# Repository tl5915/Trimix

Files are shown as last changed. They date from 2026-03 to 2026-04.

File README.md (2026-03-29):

# Trimix Analyser
Gas thermo conductivity based trimix analyser. No internal battery, powered via USB-C using phone or power bank, or Magsafe. No display, user interface accessed via html.

## Principles
### Oxygen
- Galvenic O2 cell outputs voltage roughly between 8 to 70mV. This is read by ADS1115 16 bit analog-to-digital converter, with PGA gain set to 16 (256mV range). - Rebreather O2 cells contains load resistor, no external load resistor required.
### Helium
- MD62 is a thermo conductivity CO2 sensor, but could also measure gases with thermo conductivity lower than air, ie helium. The sensor contains 2 pairs of temperature-sensitive resistors, one enclosed in known gas (compensation side), one exposed to enviroment (measurement side). Apply voltage to heat up the resistors, heat will desipate quicker in measurement side when exposed to helium, changing resistance. The subtle difference in resistance between the two resistors is measured by a balanced wheastone bridge.
- Manufacturer specification for power supply is 3.0 +/- 0.1V (attached datasheet is outdated and wrong). 3.3V power supply passing through a 1N5819 Schottky diode give just the right amount of forward voltage drop to get 2.9V. Do not use the MCU's internal 3.3V power supply, use external supply: MD62 can can drain up to 200mA.
- Wheastone bridge build contains two 2k ohm resistors, and a 500 ohm potentiometer to adjust bridge balance. I use a DS3502 digital potentiometer (10k ohm), parallel connect to 510 ohm resistor to drop total resistence to 485 ohm. Bridge voltage is read between the centre pins of MD62 and DS3502 wiper, by ADS1115, with PGA gain set to 4 (1024mV range). Maximum voltage I have seen with pure helium is around 600mV so well within range.
- Flow rate matters for thermal conductivity sensors: quickly the gas flow, quicker heat got taken away from the sensor. Ideal flow rate 0.5 to 2L/min. BCD inflator nipple to 1/4 NPT male adaptor has the perfect inner diameter to tap 3/8 UNF thread, so a low pressure port blank plug without o ring can be installed, and flow rate can be adjusted by how tight it is. Low pressure constant flow gas exit via hose barb to 1/4 NPT female adaptor. Several try and errors required to set the flow rate.
### Gas quality
- I couldn't find any small enough carbon monoxide sensor, so opted for SGP40. SGP40 is a VOC sensor, but also cross react with carbon monoxide. This might be a better option, because the sources of CO found in cylinder are usually o ring combustion, or generator/engine fume, both containing VOC.
- The sensor read out if not quantitantive, but relative. Turn on in air, reading should stablise around 50 to 100, if reading in analysed gas goes up -> bad, otherwise lower the number the better. Raw sensor resistance also provided on the UI for reference (higher the better, VOC and CO reduce resistance).
### Coomunication
- All peripheries (ADS1115, DS3502, SGP40) are connected to Adafruit QT Py ESP32-C3 through I2C, via the Stemma QT connector.
- ESP32-C3 wifi is set to AP hotspot mode, connect to the wifi and read/calibrate via html.
### Power
- USB-C panel mount connects to VCC and GND on QT Py ESP32-C3 for 5V USB power.
- Alternatively MagSafe receiver connects to the USB-C port on QT Py ESP32-C3 for wireless 5V power.

## Material
- Housing to be 3D printed in STL folder
(optional M16 x 1.0 tap to smooth out O2 connector tube)
- BCD nipple to 1.4 NPT male convertor (gas in)
(https://ebay.us/m/m2sN6S)
- 3/8 UNF tap (tap on the NPT side of the above convertor to mount a o-ring-removed LP blanking plug to adjust flow rate to 1 L/min)
(https://amzn.eu/d/0449Hkix)
- 1/4 NPT female to the smallest hose barb you can find, use barb convertor if necessary (ideally 2 mm ID silicone tubing connect to sensor chamber)
(https://ebay.us/m/jr4HbL)
- Oxygen cell, any type (molex, 3.5mm jack, coaxial), choose connector accordingly
- Wisen MD62 CO2 sensor
- 5V to 3.3V buck converter
(https://amzn.eu/d/0gPikEVZ)
- 1N5819 Schottky diode (drops the 3.3v to 3.0v that MD62 requires)
- DS3502 digital potentiometer (10k ohm), parallel connect to 510 ohm resistor to drop total resistence to 485 ohm
(https://amzn.eu/d/0adkxJX8)
- 2k ohm resistors for MD62 wheastone bridge
- SGP40 gas sensor
(https://amzn.eu/d/06vTv9tU)
- M2 screw to secure SGP40 onto sensor tube
- JST-SH 1.0 4 terminal connectors for Stemma QT
(https://amzn.eu/d/09DHS9cc)
- Adafruit ADS1115 ADC
(https://ebay.us/m/z7J8pF)
- Adafruit QT Py ESP32-C3
- USB-C panel mount
(https://amzn.eu/d/07lMHozl)
- JST-XH 2.54 2 terminal connectors for power
- Qi wireless charging receiver unit
(https://amzn.eu/d/08BN3vmo)
- MagSafe ring
(https://amzn.eu/d/02FF3lX3)

## Circuit connection
### MD62 power supply
- ESP32-C3 5V pin connects to buck converter VIN, GND pin connects to buck converter Gnd
- MD62 pin 4 connects to buck converter GND
- Buck converter VOUT connects to 1N5819 anode
- 1N5819 cathode connects to MD62 pin 1 (confirm voltage is 2.9-3.1V)
### MD62 wheastone bridge
- 2k resistor connects between MD62 pin 1 and DS3502 RL pin
- 2k resistor connects between MD62 pin 4 and DS3502 RH pin
- 510 ohm resistor connects between DS3502 RL and RH pins
- Connect MD62 pin 2 and 3
### Sensor connection
- MD62 pin 2/3 node and DS3502 pin RW connect to ADS1115 pin 0 and 1
- Oxygen sensor +/- pins connect to ADS1115 pin 2 and 3
### I2C connection
- Use Stemma QT cable to connect ESP32-C3, ADS1115, DS3502, and SGP40
### Power connection
- Crimp USB-C panel mount cables on JST-XH 2 pin male connector
- Solder JST-XH 2 pin female connector on ESP32-C3 5V and GND pins

## Housing assembly
- Insert flow adjusted BCD nipple to 1/4 NPT male adaptor to mounting hole, wrap thread with PTFE tape, thrad in 1/4 NPT female to barb adaptor from inside the case, tigthen to secure on the case
- Insert USB-C mount into the mounting hole, secure with hot glue if required
- Insert MD62 (attached to ciruit board) into mounting hole on the sensor tube
- Insert SGP40 sensor unit into mounting hole on the sensor tube, secure SGP40 with M2 screw
- Drill 3mm hole in the middle of the sensor tube, insert silicone tubing
- Insert the sensor tube assembly into mounting hole, locate the mounting hole, drill 2.5mm hole on the mounting block, secure with M3 screw
- Connect the other end of the silicone tubing to barb connector on flow limitor
- Connect molex connector to the O2 cell, screw O2 cell into the end of sensor tube
- Mount ESP32-C3 unit on the lip, secure with bracket and two M3 screws
- Connect JST-XH power cable
- Connect USB-C terminal of Qi wireless receiver to ESP32-C3
- Slide Qi wireless receiver into the narrow slot
- Mount lid onto the case, secure with four M3 screws
- Cut MagSafe ring to match the slot on the outside of the case, secure with super glue

## Usage
- Power with USB-C or MagSafe charger
- IPhone: connect to the Trimix_Analyser wifi hotspot, password 12345678; browser open 192.168.4.1, add to home screen. Open the app on home screen
- Reverse helium polarity in setting page if helium voltage is negative
- Use pure helium or standard gas trimix for helium calibration
- Helium or oxygen percentage used for two point calibration can be edited in setting page
- SGP40 reading only valid after 1 minute initialisation. This eading is not in PPM, but relative to fresh air (100), lower (towards 1) the better quality, higher (towards 500) the worse quality. Volatile organic compounds, CO, and CO2 (all gases you don't want in your cylinder) increases reading.
- Upload bin file in setting page for OTA firmware update
- Browser open 192.168.4.1/upload to upload a app icon, this can be any 180 x 180 pixel png of your choice

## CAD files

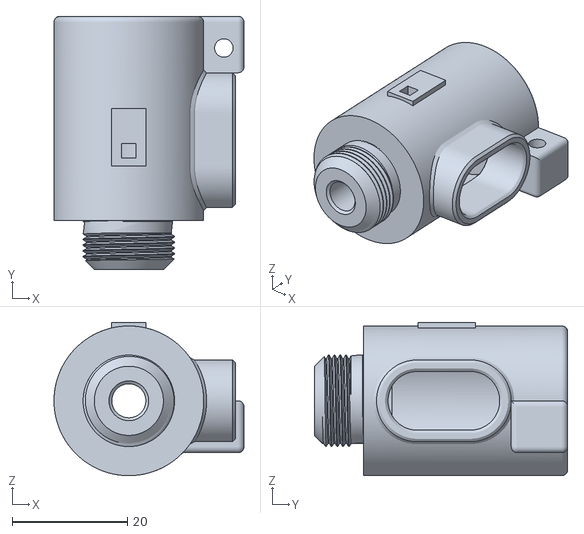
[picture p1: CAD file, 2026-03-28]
STL/Analyser/SensorTube.stl
33.0 x 44.0 x 26.6

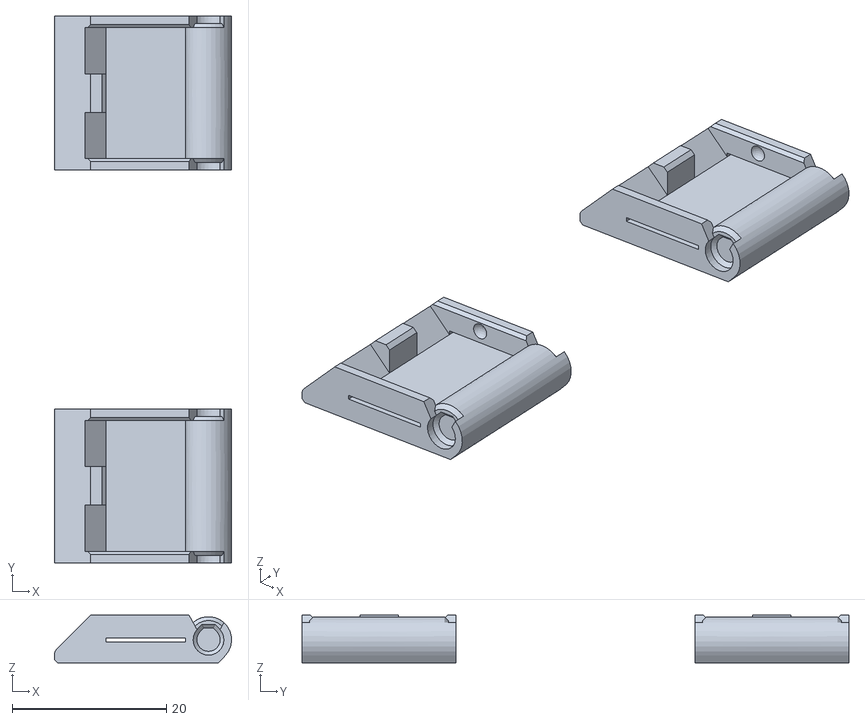
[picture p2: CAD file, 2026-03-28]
STL/Case/Case hinges.stl
23.0 x 71.0 x 6.20

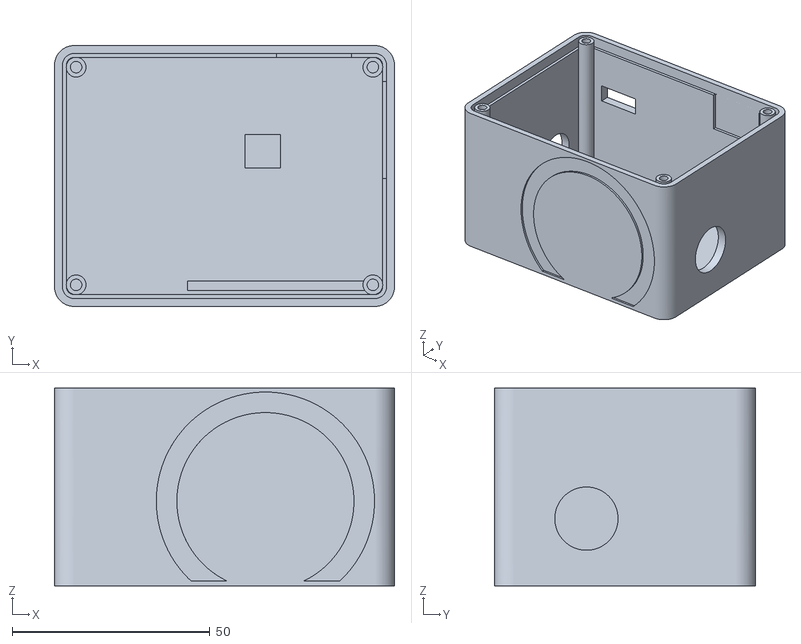
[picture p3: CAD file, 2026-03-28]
STL/Analyser/Case - Magsafe.stl
86.0 x 66.0 x 50.0

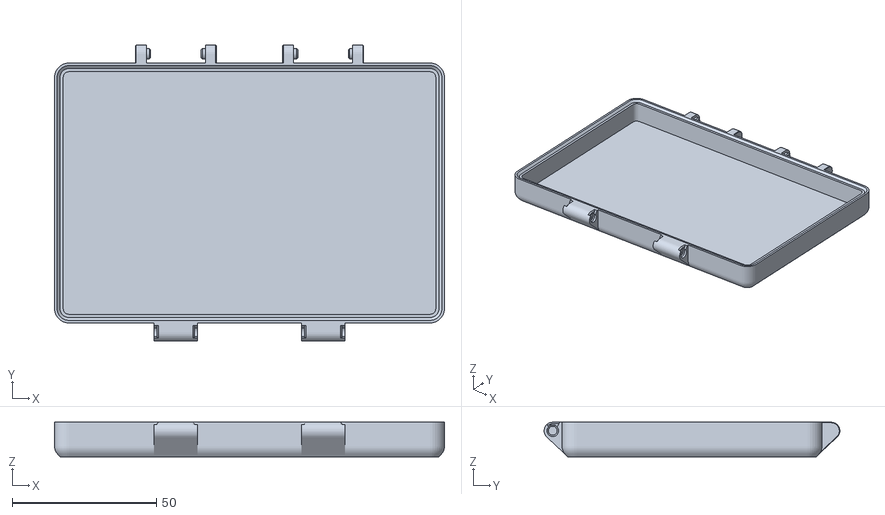
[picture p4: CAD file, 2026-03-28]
STL/Case/Case lid.stl
135.0 x 102.4 x 12.0

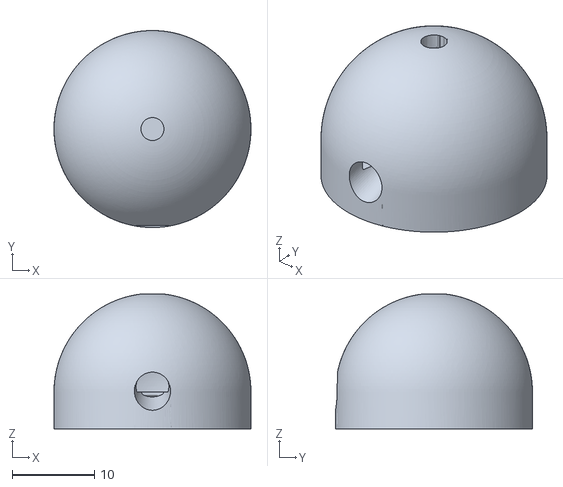
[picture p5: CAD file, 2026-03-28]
STL/Analyser/flow restrictor.stl
24.0 x 24.0 x 16.4

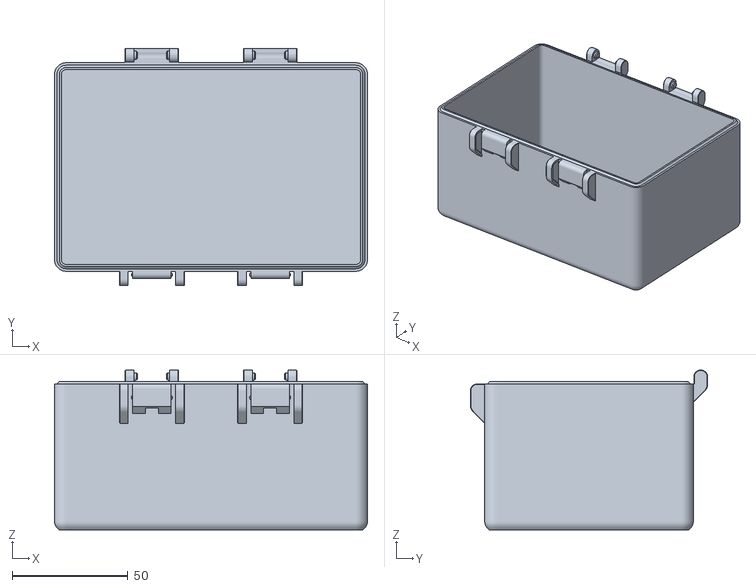
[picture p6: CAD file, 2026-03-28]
STL/Case/Case body.stl
135.0 x 102.4 x 69.0

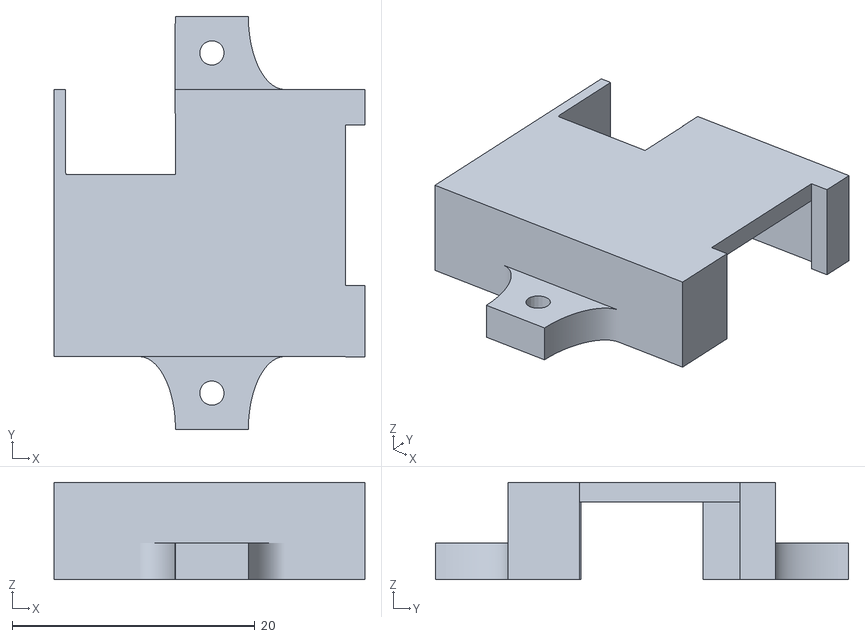
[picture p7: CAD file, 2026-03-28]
STL/Analyser/QTPy_Holder.stl
25.6 x 34.0 x 8.00

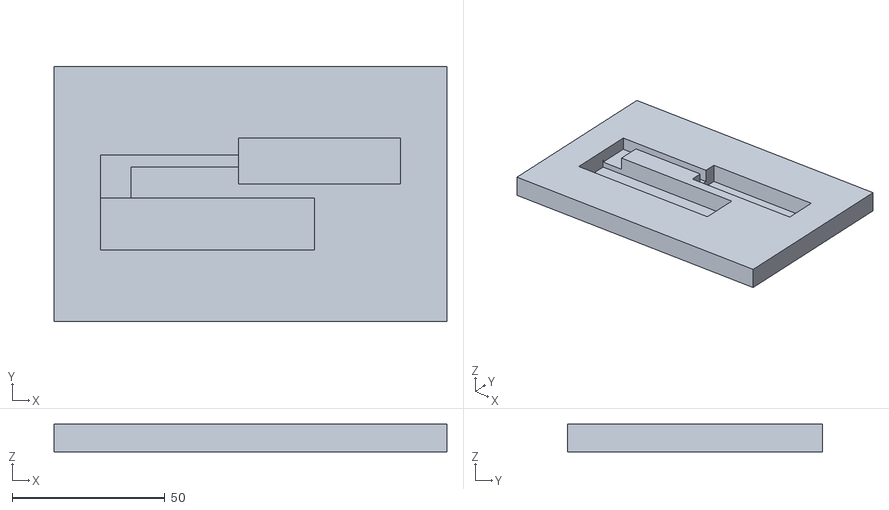
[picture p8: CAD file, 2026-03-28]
STL/Case/Insert_lid_TPU.stl
128.5 x 83.5 x 9.00

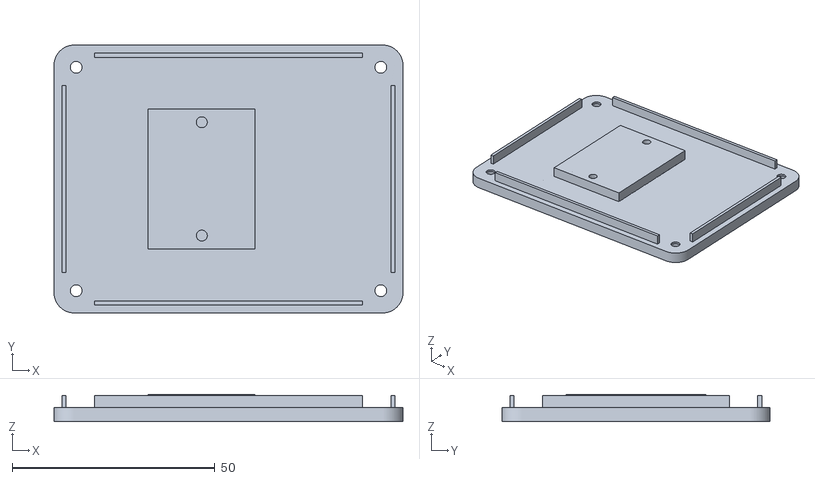
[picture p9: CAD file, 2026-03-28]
STL/Analyser/Lid.stl
86.0 x 66.0 x 6.72

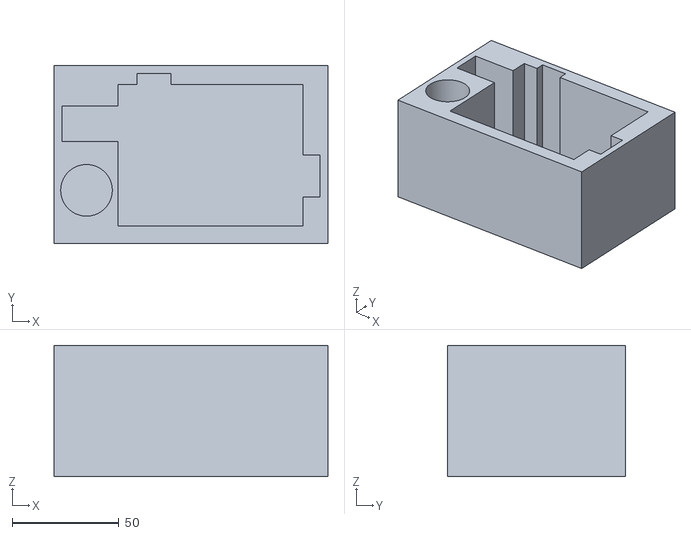
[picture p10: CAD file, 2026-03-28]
STL/Case/Insert_body_TPU.stl
128.5 x 83.5 x 61.5

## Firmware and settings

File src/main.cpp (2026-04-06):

#include <Arduino.h>
// OTA Libraries
#include <FS.h>
#include <SPIFFS.h>
#include <Update.h>
// UI Libraries
#include <WiFi.h>
#include <esp_bt.h>
#include <esp_wifi.h>
#include <WebServer.h>
// Peripheral Libraries
#include <EEPROM.h>
#include <Adafruit_DS3502.h>
#include <Adafruit_ADS1X15.h>
#include <sensirion_arch_config.h>
#include <sensirion_voc_algorithm.h>
#include <SparkFun_SGP40_Arduino_Library.h>
// HTML pages
#include "webPages.h"

// Firmware Version
#define FIRMWARE_VERSION 1.1
#define STRINGIFY(x) #x
#define TOSTRING(x)  STRINGIFY(x)

// Global Objects
WebServer server(80);
File fsUploadFile;
Adafruit_DS3502 ds3502;
Adafruit_ADS1115 ads;
SGP40 sgp40;

// Pin Definition
const uint8_t SCLPin = 6;  // GPIO 6
const uint8_t SDAPin = 5;  // GPIO 5

// EEPROM Address
const int ADDR_HELIUM_POLARITY = 0;
const int ADDR_WIPER_VALUE = 4;
const int ADDR_OXYGEN_CAL_PERCENTAGE = 8;
const int ADDR_HELIUM_CAL_PERCENTAGE = 12;
const int ADDR_OXYGEN_CAL_VOLTAGE = 16;
const int ADDR_PURE_OXYGEN_VOLTAGE = 24;
const int ADDR_HELIUM_CAL_VOLTAGE = 32;

// SPIFFS
size_t iconUploadBytes = 0;
bool iconUploadValid = true;

// Calibration
const uint8_t defaultwiperValue = 58;           // Potentiometer wiper position
const uint8_t defaultOxygenCalPercentage = 99;  // Oxygen calibration percentage
const uint8_t defaultHeliumCalPercentage = 99;  // Helium calibration percentage
const float defaultOxygenCalVoltage = 12.0;     // Oxygen voltage in air
const float defaultPureOxygenVoltage = 0.0;     // Oxygen voltage in oxygen
const float defaultHeliumCalVoltage = 620.0;    // Helium voltage in helium
bool heliumPolarity = false;
bool isTwoPointCalibrated = false;
uint8_t wiperValue = defaultwiperValue;
uint8_t bestWiperValue = wiperValue;
uint8_t OxygenCalPercentage = defaultOxygenCalPercentage; 
uint8_t HeliumCalPercentage = defaultHeliumCalPercentage;
float oxygencalVoltage = defaultOxygenCalVoltage;
float pureoxygenVoltage = defaultPureOxygenVoltage;
float heliumcalVoltage = defaultHeliumCalVoltage;

// Sampling
const uint8_t calibrationSampleCount = 20;  // Average 20 samples for calibration
const uint8_t samplingRateHz = 50;          // Sampling rate 50 Hz
const uint8_t displayRateHz = 2;            // Display refresh rate 2 Hz
unsigned long lastSampleTime = 0;
unsigned long lastDisplayUpdate = 0;
uint16_t voc = 0;
uint16_t sgpRaw = 0;
uint16_t sgpRawCorr = 0;
uint16_t sampleCount = 0;
uint16_t avgSampleCount = 0;
float oxygenVoltage = 0.0;
float oxygenSum = 0.0;
float avgOxygenVoltage = 0.0;
float oxygenPercentage = 0.0;
float heliumVoltage = 0.0;
float heliumSum = 0.0;
float avgHeliumVoltage = 0.0;
float correctedHeliumVoltage = 0.0;
float heliumPercentage = 0.0;
uint16_t mod14 = 0;
uint16_t mod16 = 0;
uint16_t mod_cc = 0;
uint16_t end = 0;
uint16_t end_cc = 0;
float den = 0.0;
float den_cc = 0.0;

// WiFi Settings
const char *ssid = "Trimix_Analyser";  // WiFi SSID
const char *password = "12345678";     // WiFi password

// Read Oxygen Voltage
float getOxygenVoltage() {
  ads.setGain(GAIN_SIXTEEN);
  int16_t oxygenRaw = ads.readADC_Differential_2_3();  // O2 pins 2 & 3
  return fabs(oxygenRaw * 0.0078125);                  // Gain 16, 256 mV
}

// Read Helium Voltage
float getHeliumVoltage() {
  ads.setGain(GAIN_FOUR);
  int16_t heliumRaw = ads.readADC_Differential_0_1();  // He pins 0 & 1
  if (heliumPolarity) {
    return -(heliumRaw * 0.03125);                     // Apply helium polarity setting
  }
  return heliumRaw * 0.03125;                          // Gain 4, 1024 mV
}

// Oxygen Percentage Calculation
float getOxygenPercentage() {
  if (!isTwoPointCalibrated) {
    return (avgOxygenVoltage / oxygencalVoltage) * 20.9;  // One-point calibration
  }
  return 20.9 + ((avgOxygenVoltage - oxygencalVoltage) / (pureoxygenVoltage - oxygencalVoltage)) * (OxygenCalPercentage - 20.9);  // Two-point calibration
}

// 21% Oxygen Calibration
void airOxygenCalibration() {
  oxygenSum = 0.0;
  for (uint8_t i = 0; i < calibrationSampleCount; i++) {
    oxygenVoltage = getOxygenVoltage();
    oxygenSum += oxygenVoltage;
    delay(20);  // 50 Hz sampling rate
  }
  oxygencalVoltage = oxygenSum / calibrationSampleCount;
  EEPROM.put(ADDR_OXYGEN_CAL_VOLTAGE, oxygencalVoltage);
  EEPROM.commit();
}

// 100% Oxygen Calibration
void pureOxygenCalibration() {
  oxygenSum = 0.0;
  for (uint8_t i = 0; i < calibrationSampleCount; i++) {
    oxygenVoltage = getOxygenVoltage();
    oxygenSum += oxygenVoltage;
    delay(20);  // 50 Hz sampling rate
  }
  float newPureVoltage = oxygenSum / calibrationSampleCount;
  if (newPureVoltage > oxygencalVoltage) {
    pureoxygenVoltage = newPureVoltage;
    isTwoPointCalibrated = true;
    EEPROM.put(ADDR_PURE_OXYGEN_VOLTAGE, pureoxygenVoltage);
    EEPROM.commit();
  }
}

// 0% Helium Calibration
void zeroHeliumCalibration() {
  uint8_t lowerLimit = 0;    // Resistor low end
  uint8_t upperLimit = 127;  // Resistor high end
  ds3502.setWiper(lowerLimit);
  delay(50);  // 50 ms delay for voltage stabilisation
  float voltageAtMin = getHeliumVoltage();
  ds3502.setWiper(upperLimit);
  delay(50);  // 50 ms delay for voltage stabilisation
  float voltageAtMax = getHeliumVoltage();
  bool potInverted = voltageAtMax < voltageAtMin;  // Determine polarity of DS3502
  float heliumZeroVoltage = 999.9;
  unsigned long calibrationStartTime = millis();
  while (lowerLimit <= upperLimit) {
    wiperValue = (lowerLimit + upperLimit) / 2;  // Start from mid-point
    ds3502.setWiper(wiperValue);
    delay(50);  // 50 ms delay for voltage stabilisation
    heliumSum = 0.0;
    for (uint8_t i = 0; i < calibrationSampleCount; i++) {
      heliumVoltage = getHeliumVoltage();
      heliumSum += heliumVoltage;
      delay(20);  // 50 Hz sampling rate
    }
    avgHeliumVoltage = heliumSum / calibrationSampleCount;
    float currentHeliumZeroVoltage = avgHeliumVoltage - 0.62;  // Helium correction factor at 21% O2
    if (currentHeliumZeroVoltage > 0 && fabs(currentHeliumZeroVoltage) < fabs(heliumZeroVoltage)) {
      heliumZeroVoltage = currentHeliumZeroVoltage;
      bestWiperValue = wiperValue;  // Find wiper position that gives lowest positive corrected helium voltage
    }
    if (!potInverted) {  // Binary search with inverted DS3502 polarity
      if (avgHeliumVoltage <= 0.62) {
        lowerLimit = wiperValue + 1;
      } else {
        upperLimit = wiperValue - 1;
      }
    } else {             // Binary search with default DS3502 polarity
      if (avgHeliumVoltage <= 0.62) {
        upperLimit = wiperValue - 1;
      } else {
        lowerLimit = wiperValue + 1;
      }
    }
  }
  ds3502.setWiper(bestWiperValue);
  EEPROM.put(ADDR_WIPER_VALUE, bestWiperValue);
  EEPROM.commit();
}

// 100% Helium Calibration
void performHeliumCalibration() {
  heliumSum = 0.0;
  for (uint8_t i = 0; i < calibrationSampleCount; i++) {
    heliumVoltage = getHeliumVoltage();
    heliumSum += heliumVoltage;
    delay(20);  // 20 ms delay between samples
  }
  float newheliumcalVoltage = (heliumSum / calibrationSampleCount) - (17.0 / (1 + exp(0.105 * (0.3240 * HeliumCalPercentage + 19.455))));  // Calibration factor based on standard gas
  if (newheliumcalVoltage > 50) {
    heliumcalVoltage = newheliumcalVoltage;  // 50 mV threshold for invalid helium calibration
    EEPROM.put(ADDR_HELIUM_CAL_VOLTAGE, heliumcalVoltage);
    EEPROM.commit();
  }
}

// Reset to Default
void resetToDefaultCalibration() {
  EEPROM.put(ADDR_HELIUM_POLARITY, false);
  EEPROM.put(ADDR_WIPER_VALUE, defaultwiperValue);
  EEPROM.put(ADDR_OXYGEN_CAL_PERCENTAGE, defaultOxygenCalPercentage);
  EEPROM.put(ADDR_HELIUM_CAL_PERCENTAGE, defaultHeliumCalPercentage);
  EEPROM.put(ADDR_OXYGEN_CAL_VOLTAGE, defaultOxygenCalVoltage);
  EEPROM.put(ADDR_PURE_OXYGEN_VOLTAGE, defaultPureOxygenVoltage);
  EEPROM.put(ADDR_HELIUM_CAL_VOLTAGE, defaultHeliumCalVoltage);
  EEPROM.commit();
  esp_restart();  // Restart after reset
}

// Oxygen Calibration Percentage
void setOxygenCalibration() {
  if (server.hasArg("OxygenCalPercentage")) {
    OxygenCalPercentage = server.arg("OxygenCalPercentage").toInt();
    EEPROM.put(ADDR_OXYGEN_CAL_PERCENTAGE, OxygenCalPercentage);
    EEPROM.commit();
    String response = "<html><body><h1>Saved!</h1><p>Rebooting</p></body></html>";
    server.send(200, "text/html", response);
    esp_restart();
  } else {
    server.send(400, "text/html", "<html><body><h1>Error:</h1><p>Missing parameter.</p></body></html>");
  }
}

// Helium Calibration Percentage
void setHeliumCalibration() {
  if (server.hasArg("HeliumCalPercentage")) {
    HeliumCalPercentage = server.arg("HeliumCalPercentage").toInt();
    EEPROM.put(ADDR_HELIUM_CAL_PERCENTAGE, HeliumCalPercentage);
    EEPROM.commit();
    String response = "<html><body><h1>Saved!</h1><p>Rebooting</p></body></html>";
    server.send(200, "text/html", response);
    esp_restart();
  } else {
    server.send(400, "text/html", "<html><body><h1>Error:</h1><p>Missing parameter.</p></body></html>");
  }
}

// Helium Sensor Polarity
void setHeliumPolarity() {
  if (server.hasArg("HeliumPolarity")) {
    int polarityInput = server.arg("HeliumPolarity").toInt();
    polarityInput = (polarityInput == 1) ? 1 : 0;
    heliumPolarity = (polarityInput == 1);  // 0 = false (default), 1 = true (reverse)
    EEPROM.put(ADDR_HELIUM_POLARITY, heliumPolarity);
    EEPROM.commit();
    String response = "<html><body><h1>Saved!</h1><p>Rebooting</p></body></html>";
    server.send(200, "text/html", response);
    esp_restart();
  } else {
    server.send(400, "text/html", "<html><body><h1>Error:</h1><p>Missing parameter.</p></body></html>");
  }
}

// Format Time
String formatTime() {
  unsigned long seconds = millis() / 1000;
  unsigned long minutes = seconds / 60;
  if (minutes > 99) {
    minutes = 99;
    seconds = 59;
  } else {
    seconds = seconds % 60;
  }
  String timeString = "";
  timeString += String(minutes) + ":";
  if (seconds < 10) {
    timeString += "0";
  }
  timeString += String(seconds);
  return timeString;
}

// Send data to client
void handleData() {
  String json = "{";
  json += "\"time\":\"" + formatTime() + "\",";
  json += "\"count\":\"" + String(avgSampleCount) + "\",";
  json += "\"voc\":\"" + String(voc) + "\",";
  json += "\"sgpRawCorr\":\"" + String(sgpRawCorr) + "\",";
  json += "\"oxygen\":\"" + String(getOxygenPercentage(), 1) + "\",";
  json += "\"helium\":\"" + String(heliumPercentage, 1) + "\",";
  json += "\"avgOxygenVoltage\":\"" + String(avgOxygenVoltage, 2) + "\",";
  json += "\"correctedHeliumVoltage\":\"" + String(correctedHeliumVoltage, 2) + "\",";
  json += "\"mod14\":\"" + String(mod14) + "\",";
  json += "\"mod16\":\"" + String(mod16) + "\",";
  json += "\"end\":\"" + String(end) + "\",";
  json += "\"density\":\"" + String(den, 1) + "\",";
  json += "\"mod_cc\":\"" + String(mod_cc) + "\",";
  json += "\"end_cc\":\"" + String(end_cc) + "\",";
  json += "\"density_cc\":\"" + String(den_cc, 1) + "\",";
  json += "\"oxygencalVoltage\":\"" + String(oxygencalVoltage, 2) + "\",";
  json += "\"pureoxygenVoltage\":\"" + String(pureoxygenVoltage, 2) + "\",";
  json += "\"heliumcalVoltage\":\"" + String(heliumcalVoltage, 2) + "\",";
  json += "\"bestWiperValue\":\"" + String(bestWiperValue) + "\"";
  json += "\"OxygenCalPercentage\":\"" + String(OxygenCalPercentage) + "\",";
  json += "\"HeliumCalPercentage\":\"" + String(HeliumCalPercentage) + "\",";
  json += "}";
  server.send(200, "application/json", json);
}

// Firmware Update
void handleOTAUpload() {
  HTTPUpload& upload = server.upload();
  switch (upload.status) {
    case UPLOAD_FILE_START:
      Serial.printf("OTA: Begin %s\n", upload.filename.c_str());
      if (!Update.begin(UPDATE_SIZE_UNKNOWN)) {
        Update.printError(Serial);
      }
      break;
    case UPLOAD_FILE_WRITE:
      if (Update.write(upload.buf, upload.currentSize) != upload.currentSize) {
        Update.printError(Serial);
      }
      break;
    case UPLOAD_FILE_END:
      if (Update.end(true)) {  // true = reboot when done
        Serial.printf("OTA: Success, %u bytes\n", upload.totalSize);
      } else {
        Update.printError(Serial);
      }
      break;
    default:
      break;
  }
}

void handleOTAFinish() {
  server.sendHeader("Connection", "close");
  if (Update.hasError()) {
    server.send(200, "text/plain", "Update Failed");
  } else {
    server.send(200, "text/plain", "Update Successful. Rebooting...");
  }
  delay(100);
  ESP.restart();
}

// Get Icon File
void handleUpload() {
  HTTPUpload& upload = server.upload();
  if (upload.status == UPLOAD_FILE_START) {
    iconUploadBytes = 0;
    iconUploadValid = true;
    if (SPIFFS.exists("/icon.png")) {
      SPIFFS.remove("/icon.png");
    }
    fsUploadFile = SPIFFS.open("/icon.png", FILE_WRITE);
    if (!fsUploadFile) {
      iconUploadValid = false;
    }
  } else if (upload.status == UPLOAD_FILE_WRITE) {
    if (!iconUploadValid || !fsUploadFile) {
      return;
    }
    iconUploadBytes += upload.currentSize;
    if (iconUploadBytes > (20 * 1024)) {
      iconUploadValid = false;
      fsUploadFile.close();
      SPIFFS.remove("/icon.png");
      return;
    }
    if (fsUploadFile.write(upload.buf, upload.currentSize) != upload.currentSize) {
      iconUploadValid = false;
      fsUploadFile.close();
      SPIFFS.remove("/icon.png");
    }
  } else if (upload.status == UPLOAD_FILE_END) {
    if (fsUploadFile) {
      fsUploadFile.close();
    }
    if (iconUploadBytes == 0) {
      iconUploadValid = false;
      SPIFFS.remove("/icon.png");
    }
  } else if (upload.status == UPLOAD_FILE_ABORTED) {
    iconUploadValid = false;
    if (fsUploadFile) {
      fsUploadFile.close();
    }
    SPIFFS.remove("/icon.png");
  }
}
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
void loop() {
  unsigned long currentTime = millis();

  // HTML update
  server.handleClient();

  // Sensor sampling
  if (currentTime - lastSampleTime >= (1000 / samplingRateHz)) {
    lastSampleTime = currentTime;
    if (sampleCount == 0) {
      oxygenSum = heliumSum = 0.0;
    }
    oxygenVoltage = getOxygenVoltage();
    oxygenSum += oxygenVoltage;
    heliumVoltage = getHeliumVoltage();
    heliumSum += heliumVoltage;
    sampleCount++;
  }

  // Update cycle
  if (currentTime - lastDisplayUpdate >= (1000 / displayRateHz)) {
    lastDisplayUpdate = currentTime;

    // Get Time
    String elapsedTime = formatTime();

    // Get Gas Quality, 0% humidity, 20 degree Celsius
    voc = sgp40.getVOCindex(0, 20);    // VOC index
    if (voc < 1) {
      voc = 1;                         // VOC index minimum 1
    } else if (voc > 500) {
      voc = 500;                       // VOC index maximum 500
    }
    sgp40.measureRaw(&sgpRaw, 0, 20);  // Raw reading
    if (sgpRaw < 20001) {
      sgpRaw = 20001;                  // Raw reading minimum 20001
    } else if (sgpRaw > 52767) {
      sgpRaw = 52767;                  // Raw reading maximum 52767
    }
    sgpRawCorr = sgpRaw - 20000;       // Corrected range 1-32767

    // Calculate average voltages
    avgOxygenVoltage = (sampleCount > 0) ? (oxygenSum / sampleCount) : 0.0;
    if (avgOxygenVoltage > 99.9) {
      avgOxygenVoltage = 99.9;   // Maximum oxygen voltage allowed 99.9 mV
    }
    avgHeliumVoltage = (sampleCount > 0) ? (heliumSum / sampleCount) : 0.0;
    avgSampleCount = sampleCount;
    sampleCount = 0;

    // Calculate oxygen percentage
    oxygenPercentage = getOxygenPercentage();
    if (oxygenPercentage < 0.0) {
      oxygenPercentage = 0.0;  // Minimum oxygen percentage allowed 0%
    }

    // Calculate helium percentage
    correctedHeliumVoltage = avgHeliumVoltage - (17.0 / (1 + exp(-0.105 * (oxygenPercentage - 52.095))));  // Helium correction factor based on oxygen percentage
    if (correctedHeliumVoltage > 999.9) {
      correctedHeliumVoltage = 999.9;   // Maximum helium voltage allowed 999.9 mV
    } else if (correctedHeliumVoltage < -999.0) {
      correctedHeliumVoltage = -999.0;  // Minimum helium voltage allowed -999.0 mV if helium sensor polarity is inverted
    }    
    heliumPercentage = (correctedHeliumVoltage > 0.0) ? (correctedHeliumVoltage / heliumcalVoltage) * HeliumCalPercentage : 0.0;
    if (heliumPercentage < 2.0) {
      heliumPercentage = 0.0;  // Minimum helium percentage allowed 0%, treat <2% as 0%
    }

    // Calculate MOD
    mod14 = (oxygenPercentage > 0) ? (int)((1400.0 / oxygenPercentage) - 10.0) : 0;  // MOD at ppO2 1.4
    if (mod14 > 999) {
      mod14 = 999;  // Maximum MOD allowed 999 m
    }
    mod16 = (oxygenPercentage > 0) ? (int)((1600.0 / oxygenPercentage) - 10.0) : 0;  // MOD at ppO2 1.6
    if (mod16 > 999) {
      mod16 = 999;  // Maximum MOD allowed 999 m
    }
    mod_cc = (oxygenPercentage > 0) ? (int)((1200.0 / oxygenPercentage) - 10.0) : 0;  // MOD at ppO2 1.2
    if (mod_cc > 999) {
      mod_cc = 999;  // Maximum MOD allowed 999 m
    }

    // Calculate END
    end = (mod14 + 10.0) * (1 - heliumPercentage / 100.0) - 10.0;  // END at MOD 1.4
    if (end < 0) {
      end = 0;  // Minimum END allowed 0 m
    }
    end_cc = (mod_cc + 10.0) * (1 - heliumPercentage / 100.0) - 10.0;  // END at MOD 1.2
    if (end_cc < 0) {
      end_cc = 0;  // Minimum END allowed 0 m
    }

    // Calculate Density
    den = (oxygenPercentage * 0.1756 - heliumPercentage * 1.0582 + 123.46) * (mod14 + 10) / 1000;  // Density at MOD 1.4
    if (den > 99.9) {
      den = 99.9;  // Maximum density allowed 99.9 g/L
    }
    den_cc = (oxygenPercentage * 0.1756 - heliumPercentage * 1.0582 + 123.46) * (mod_cc + 10) / 1000;  // Density at MOD 1.2
    if (den_cc > 99.9) {
      den_cc = 99.9;  // Maximum density allowed 99.9 g/L
    }
  }
}

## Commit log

2026-03-17 update default calibration values
2026-03-26 Add gas calculation of closed circuit (ppO2 1.2)
2026-03-27 Close circuit support 1st build
2026-03-28 Include 3D printed parts STL files
    [Case - Magsafe.stl, Case body.stl, Case hinges.stl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]
